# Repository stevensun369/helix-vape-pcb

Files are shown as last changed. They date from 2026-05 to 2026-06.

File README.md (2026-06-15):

# Helix Vape — Power Board

KiCad hardware design for the **Helix** temperature-control vape mod: a single-cell, USB-C powered board capable of delivering **1.0–10 V at up to 80 W** into a heating coil, with closed-loop current/voltage sensing and an ESP32-C6 running the [Helix-FW](https://github.com/stevensun369/helix-vape-fw) firmware.

The power stage is based on TI's **PMP20410** reference design, re-implemented and integrated with the MCU, sensing, and user-interface circuitry on a single board.

## Renders

| Front | Back |
|---|---|
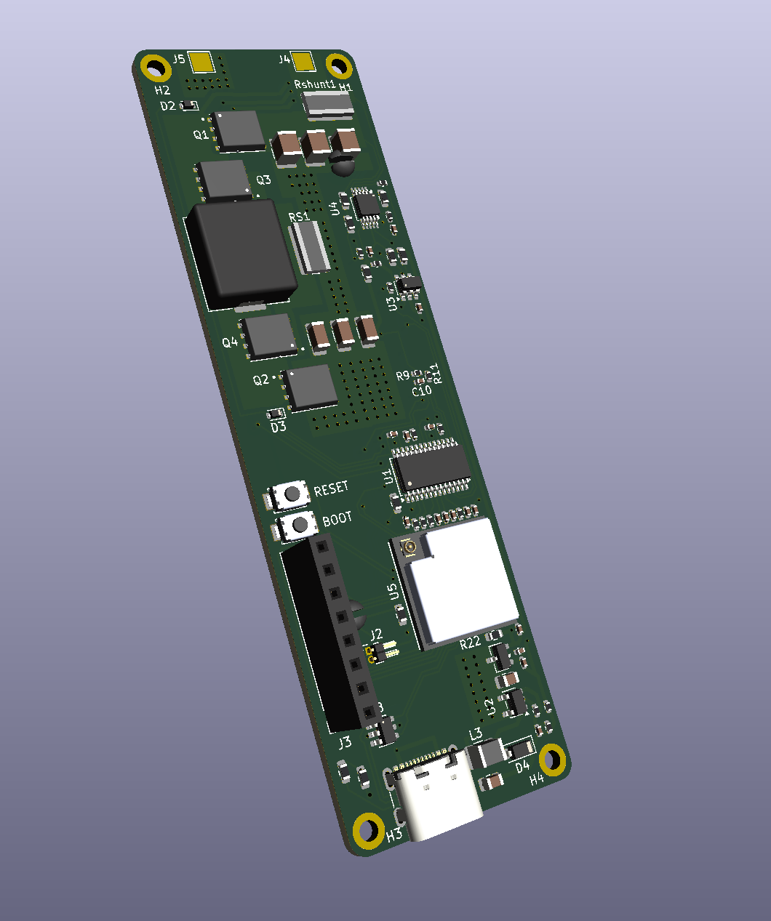
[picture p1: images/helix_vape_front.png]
Front render
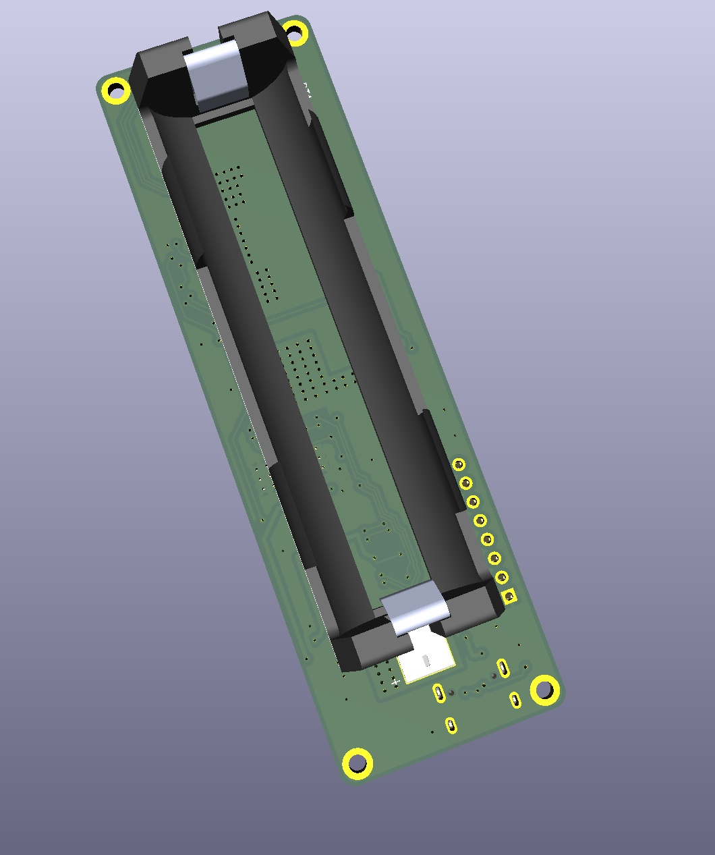
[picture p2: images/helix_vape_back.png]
Back render
|  |  |

## Schematics

| Power & analog front-end | MCU & digital |
|---|---|
| Power schematic | MCU schematic |

> Click either schematic to open the full-size SVG.

## How It Works

The board is a **digitally-controlled buck-boost regulator**. The MCU sets a target output via a DAC that injects into the regulator's feedback node, the ADC measures the actual coil current and voltage, and the firmware closes the loop with a PID controller. Because the regulator both bucks and boosts, it can hold a precise output regardless of where the battery sits in its discharge curve.

```
USB-C / Battery ──► LM5175 Buck-Boost ──► Q1–Q4 Power FETs ──► Coil
                         ▲                        │
                    MCP4726 DAC          RS1 / Rshunt sense
                         │                        │
                    ESP32-C6 ◄──────── ADS1015 ADC
```

## Key Components

| Ref | Part | Function |
|-----|---|---|
| U1 | **LM5175PWP** | 4-switch synchronous buck-boost controller — the main 80 W power stage |
| U5 | **ESP32-C6-MINI-1U** | RISC-V MCU + Wi-Fi/BLE module; runs the control loop, UI, and safety logic |
| U4 | **ADS1015IDGS** | 12-bit I²C ADC — differential coil-current sensing plus single-ended Vout/Vbat |
| U3 | **MCP4726** | 12-bit I²C DAC — injects into the LM5175 feedback node to set output (inverse scaling) |
| Q1–Q4 | **BSC010NE2LSI** | 25 V, ~1 mΩ power MOSFETs — the buck-boost switching bridge |
| U2 | **LMR62014XMF** | Boost regulator for the auxiliary/gate-drive rail |
| U6 | **LP3986-30B3F** | 3.0 V LDO — clean rail for the MCU and analog parts |
| U8 | **USBLC6-2SC6** | USB-C data-line ESD / TVS protection |
| J1 | **USB-C Receptacle (16P)** | Charging and power input |
| RS1 / Rshunt1 | **2 mΩ / 10 mΩ shunts** | High-side and coil current sensing |
| L1 | **680 nH, 23 A** | Main power inductor (Chilisin) |
| BT1 | **1042 cell** | Battery connection |
| SW1 / SW2 | Push buttons | User input |

Full bill of materials with LCSC part numbers is in [`PRODUCTION_FILES/BOM-helix_vape.csv`](PRODUCTION_FILES/BOM-helix_vape.csv).

## Design Notes

- **Inverse DAC feedback:** higher DAC voltage produces *lower* output, so any logical fault or DAC reset biases the regulator toward a safe low-power idle (~1.0 V) rather than full power.
- **Shared I²C bus @ 400 kHz** ties together the ADC and DAC; the firmware arbitrates access to keep latency predictable under contention.
- **Differential current sensing** through the ADS1015 gives the firmware accurate, real-time coil current for PID power control and over-current safety.

## Files

| Path | Contents |
|---|---|
| `helix_vape.kicad_pro` / `.kicad_sch` / `.kicad_pcb` | KiCad project, schematics, and board layout |
| `mcu.kicad_sch` | MCU subsheet |
| `PRODUCTION_FILES/` | Gerbers, BOM, and CPL (pick-and-place) for JLCPCB |
| `jlcpcb/` | JLCPCB fabrication / assembly outputs |
| `images/` | 3D renders and exported schematics |

## Manufacturing

Production files target **JLCPCB** assembly:

- `PRODUCTION_FILES/GERBER-helix_vape.zip` — fabrication Gerbers
- `PRODUCTION_FILES/BOM-helix_vape.csv` — bill of materials (LCSC part numbers)
- `PRODUCTION_FILES/CPL-helix_vape.csv` — component placement / pick-and-place

## Firmware

The board is driven by [Helix-FW](https://github.com/stevensun369/helix-vape-fw), an async Rust (Embassy) firmware with a host-testable safety and control logic core.

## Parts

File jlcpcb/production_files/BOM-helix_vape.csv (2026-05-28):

Comment | Designator | Footprint | LCSC | Quantity
0 | R7 | R_0402_1005Metric | C881153 | 1
0.022uF | C8 | C_0402_1005Metric | C107019 | 1
0.047uF | C7 | C_0402_1005Metric | C285062 | 1
0.1uF | C20,C22,C23 | C_0402_1005Metric | C1525 | 3
0.1uF | C2,C5,C9 | C_0402_1005Metric | C85858 | 3
0.22uF | C3,C6 | C_0402_1005Metric | C696915 | 2
1.5k | R5 | R_0402_1005Metric | C308014 | 1
10 | R1,R2,R3 | R_0402_1005Metric | C176108 | 3
100 | R11,R9 | R_0402_1005Metric | C82865 | 2
100k | R28 | R_0603_1608Metric | C25803 | 1
100pF | C1,C11 | C_0402_1005Metric | C281751 | 2
1042 | BT1 | BAT_1042 | C5249310 | 1
10k | R22,R23,R4,R6 | R_0603_1608Metric | C25804 | 4
10m | Rshunt1 | R_1225_3264Metric | C304202 | 1
10uH | L3 | L_1210_3225Metric | C22469024 | 1
120k | R26 | R_0603_1608Metric | C25808 | 1
130k | R13 | R_0402_1005Metric | C881362 | 1
16.2k | R16 | R_0402_1005Metric | C27176 | 1
1uF | C4 | R_0402_1005Metric | C29266 | 1
2.2uF | C24,C25 | C_0402_1005Metric | C12530 | 2
200k | R29 | R_0402_1005Metric | C25811 | 1
20k | R14 | R_0402_1005Metric | C5157652 | 1
220pF | C10 | C_0402_1005Metric | C1530 | 1
22uF | Cout1,Cout2,Cout3 | C_1210_3225Metric | C2918511 | 3
22uF | Cin1,Cin2,Cin3 | C_1206_3216Metric | C87996 | 3
2m | RS1 | R_1225_3264Metric | C7463342 | 1
4.7k | R24,R25 | R_0603_1608Metric | C23162 | 2
4.7uF | Cin4,Cout6 | C_0805_2012Metric | C107365 | 2
47 | R8 | R_0603_1608Metric | C23182 | 1
47k | R27 | R_0402_1005Metric | C25819 | 1
49.9k | R10 | R_0603_1608Metric | C23184 | 1
49.9k | R18 | R_0402_1005Metric | C3008853 | 1
5.1k | R20,R21 | R_0603_1608Metric | C14677 | 2
5.49k | R15 | R_0402_1005Metric | C407675 | 1
560pF | C14 | C_0402_1005Metric | C107029 | 1
6.98k | R19 | R_0402_1005Metric | C852901 | 1
680nH, 23A, 30A Isat | L1 | L_Chilisin_BMRF00101040 | C2921223 | 1
68pF | C13 | C_0402_1005Metric | C76977 | 1
ADS1015IDGS | U4 | TSSOP-10_3x3mm_P0.5mm | C193969 | 1
BASS516,115 | D2,D3 | D_SOD-523 | C10037 | 2
BSC010NE2LSI | Q1,Q2,Q3,Q4 | TRANS_BSC010NE2LSI | C534282 | 4
ESP32-C6-MINI-1U | U5 | MOD53_ESP32-C6-MINI-1U_EXP | C20627095 | 1
LM5175PWP | U1 | HTSSOP-28-1EP_4.4x9.7mm_P0.65mm_EP3.4x9.5mm_ThermalVias | C113356 | 1
LMR62014XMF | U2 | SOT-23-5 | C468235 | 1
LP3986-30B3F | U6 | SOT-23-3 | C387690 | 1
MBR0520LT1G | D4 | D_SOD-123 | C23848 | 1
MCP4726 | U3 | SOT-23-6 | C191581 | 1
SW_Push | SW1,SW2 | SW_TS-1088-AR02016 | C720477 | 2
USB-C Receptacle 16P | J1 | USB_C_Receptacle_GCT_USB4105-xx-A_16P_TopMnt_Horizontal | C2765186 | 1
USBLC6-2SC6 | U8 | SOT-23-6 | C7519 | 1
510 Power | J4 | TestPoint_Pad_2.5x2.5mm |  | 1
510 Ground | J5 | TestPoint_Pad_2.5x2.5mm |  | 1
Fire Button | J2 | PinHeader_1x02_P2.54mm_Vertical |  | 1
OLED 0.96" Display | J3 | PinHeader_1x08_P2.54mm_Vertical |  | 1

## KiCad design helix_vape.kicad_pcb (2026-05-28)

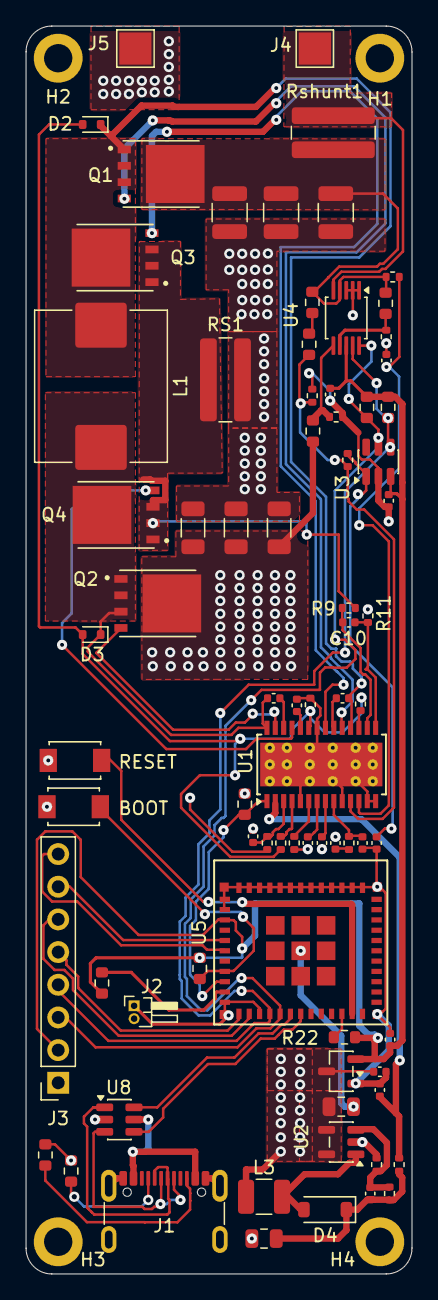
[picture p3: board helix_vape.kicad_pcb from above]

Board: 2 copper layers, 30.0 x 97.0 mm, 83 parts (1 on the bottom side), 54 nets.

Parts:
BT1: 1042; BAT_1042
C1, C11: 100pF; C_0402_1005Metric
C2, C5, C9, C20, C22, C23: 0.1uF; C_0402_1005Metric
C3, C6: 0.22uF; C_0402_1005Metric
C4: 1uF; R_0402_1005Metric
C7: 0.047uF; C_0402_1005Metric
C8: 0.022uF; C_0402_1005Metric
C10: 220pF; C_0402_1005Metric
C13: 68pF; C_0402_1005Metric
C14: 560pF; C_0402_1005Metric
C24, C25: 2.2uF; C_0402_1005Metric
Cin1, Cin2, Cin3: 22uF; C_1206_3216Metric
Cin4: 4.7uF; C_0805_2012Metric
Cout1, Cout2, Cout3: 22uF; C_1210_3225Metric
Cout6: 4.7uF; C_0805_2012Metric
D2, D3: BASS516,115; D_SOD-523
D4: MBR0520LT1G; D_SOD-123
H1, H2, H3, H4: MountingHole_Pad; MountingHole_2.2mm_M2_DIN965_Pad
J1: USB-C Receptacle 16P; USB_C_Receptacle_GCT_USB4105-xx-A_16P_TopMnt_Horizontal
J2: Fire Button; PinHeader_1x02_P1.00mm_Horizontal
J3: OLED 0.96" Display; PinSocket_1x08_P2.54mm_Vertical
J4: 510 Power; TestPoint_Pad_2.5x2.5mm
J5: 510 Ground; TestPoint_Pad_2.5x2.5mm
L1: 680nH, 23A, 30A Isat; L_Chilisin_BMRF00101040
L3: 10uH; L_1210_3225Metric
Q1, Q2, Q3, Q4: BSC010NE2LSI; TRANS_BSC010NE2LSI
R1, R2, R3: 10; R_0402_1005Metric
R4, R6, R22, R23: 10k; R_0603_1608Metric
R5: 1.5k; R_0402_1005Metric
R7: 0; R_0402_1005Metric
R8: 47; R_0603_1608Metric
R9, R11: 100; R_0402_1005Metric
R10: 49.9k; R_0603_1608Metric
R13: 130k; R_0402_1005Metric
R14: 20k; R_0402_1005Metric
R15: 5.49k; R_0402_1005Metric
R16: 16.2k; R_0402_1005Metric
R18: 49.9k; R_0402_1005Metric
R19: 6.98k; R_0402_1005Metric
R20, R21: 5.1k; R_0603_1608Metric
R24, R25: 4.7k; R_0603_1608Metric
R26: 120k; R_0603_1608Metric
R27: 47k; R_0402_1005Metric
R28: 100k; R_0603_1608Metric
R29: 200k; R_0402_1005Metric
RS1: 2m; R_1225_3264Metric
Rshunt1: 10m; R_1225_3264Metric
SW1, SW2: SW_Push; SW_TS-1088-AR02016
U1: LM5175PWP; HTSSOP-28-1EP_4.4x9.7mm_P0.65mm_EP3.4x9.5mm_ThermalVias
U2: LMR62014XMF; SOT-23-5
U3: MCP4726; SOT-23-6
U4: ADS1015IDGS; TSSOP-10_3x3mm_P0.5mm
U5: ESP32-C6-MINI-1U; MOD53_ESP32-C6-MINI-1U_EXP
U6: LP3986-30B3F; SOT-23-3
U8: USBLC6-2SC6; SOT-23-6

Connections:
+3V3: C20.1, C23.1, C25.1, J3.2, R4.1, R22.1, R23.1, R24.1, R25.1, U3.3 (VDD), U4.8 (VDD), U5.3 (3V3), U6.2 (VO)
+5V: J1.A4 (VBUS), J1.A9 (VBUS), J1.B4 (VBUS), J1.B9 (VBUS), U8.5 (VBUS)
+10V: C14.1, Cout6.1, D4.1 (K), R2.1, R18.1
ADC_IN: R28.2, R29.1, U4.6 (AIN2)
ADC_OUT: R26.2, R27.1, U4.7 (AIN3)
ADC_SH_IN: Cout1.1, Cout2.1, Cout3.1, Q1.5_8, R1.1, R8.1, R26.1, Rshunt1.1, U4.4 (AIN0)
ADC_SH_OUT: J4.1 (Pin_1_1), Rshunt1.2, U4.5 (AIN1)
BIAS: C3.1, U1.24 (BIAS)
BOOT: SW1.1, U5.23 (IO9)
BOOT1: C9.2, U1.26 (BOOT1)
BOOT2: C5.2, U1.20 (BOOT2)
COMP: C8.1, R5.2, U1.9 (COMP)
CONV_FB: C22.1, R16.2, U3.1 (VOUT)
CS: C10.1, R9.1, U1.16 (CS)
CSG: C10.2, R11.1, U1.15 (CSG)
EN: R6.1, U1.1 (EN/UVLO), U5.9 (IO4)
FB: R10.2, R15.1, R16.1, U1.11 (FB)
FIRE: J2.2, R4.2, U5.10 (IO5)
GND: BT1.N, C1.2, C2.2, C3.2, C4.2, C6.2, C7.2, C8.2, C11.2, C13.2, C20.2, C22.2, C23.2, C24.2, C25.2, Cin1.2, Cin2.2, Cin3.2, Cin4.2, Cout1.2, Cout2.2, Cout3.2, Cout6.2, H1.1 (1_1), H2.1 (1_1), H3.1 (1_1), H4.1 (1_1), J1.A1 (GND), J1.A12 (GND), J1.B1 (GND), J1.B12 (GND), J1.SH (SHIELD), J2.1, J3.1, J5.1 (Pin_1_1), R6.2, R11.2, R13.2, R15.2, R19.2, R20.2, R21.2, R27.2, R29.2, RS1.2, SW1.2, SW2.2, U1.5 (DITH), U1.10 (AGND), U1.13 (ISNS(-)), U1.14 (ISNS(+)), U1.22 (PGND), U1.29 (PowerPAD), U2.2 (GND), U3.2 (VSS), U4.1 (ADDR), U4.2 (ALERT/RDY), U4.3 (GND), U5.1 (GND), U5.2 (GND), U5.11 (GND), U5.14 (GND), U5.36 (GND), U5.37 (GND), U5.38 (GND), U5.39 (GND), U5.40 (GND), U5.41 (GND), U5.42 (GND), U5.43 (GND), U5.44 (GND), U5.45 (GND), U5.46 (GND), U5.47 (GND), U5.48 (GND), U5.49 (GND), U5.50 (GND), U5.51 (GND), U5.52 (GND), U5.53 (GND), U6.1 (GND), U8.2 (GND)
HDRV1: Q2.4, U1.27 (HDRV1)
HDRV2: Q1.4, U1.19 (HDRV2)
K1: J3.5, U5.12 (IO0)
K2: J3.6, U5.13 (IO1)
K3: J3.7, U5.5 (IO2)
K4: J3.8, U5.6 (IO3)
LDRV1: Q4.4, U1.25 (LDRV1)
LDRV2: Q3.4, U1.21 (LDRV2)
MODE: R7.2, U1.4 (MODE)
unnamed: C7.1, R5.1
unnamed: D4.2 (A), L3.2, U2.1 (SW)
unnamed: J1.A5 (CC1), R20.1
unnamed: J1.B5 (CC2), R21.1
unnamed: J1.A6 (D+), J1.B6 (D+), U8.3 (I/O2)
unnamed: J1.A7 (D-), J1.B7 (D-), U8.1 (I/O1)
unnamed: R8.2, R10.1
unnamed: R14.2, U1.17 (PGOOD)
unnamed: C13.1, U1.7 (SLOPE)
unnamed: C14.2, R18.2, R19.1, U2.3 (FB)
unnamed: R22.2, U5.22 (IO8)
RESET: R23.2, SW2.1, U5.8 (EN)
SCL: J3.3, R25.2, U3.5 (SCL), U4.10 (SCL), U5.16 (IO7)
SDA: J3.4, R24.2, U3.4 (SDA), U4.9 (SDA), U5.15 (IO6)
SS: C6.1, U1.8 (SS)
SW1: C9.1, D3.1 (K), L1.1, Q2.1, Q2.2, Q2.3, Q4.5_8, U1.28 (SW1)
SW2: C5.1, D2.1 (K), L1.2, Q1.1, Q1.2, Q1.3, Q3.5_8, U1.18 (SW2)
SYNC: R13.1, U1.6 (RT/SYNC)
USB_D+: U5.18 (IO13), U8.4 (I/O2)
USB_D-: U5.17 (IO12), U8.6 (I/O1)
VCC: C4.1, D2.2 (A), D3.2 (A), R7.1, R14.1, U1.23 (VCC)
VIN: BT1.P, C24.1, Cin1.1, Cin2.1, Cin3.1, Cin4.1, L3.1, Q2.5_8, R3.1, R28.1, U2.4 (EN), U2.5 (VIN), U6.3 (VI)
VIN_IC: C2.1, R2.2, U1.2 (VIN)
VISNS: C11.1, R3.2, U1.3 (VISNS)
VOSNS: C1.1, R1.2, U1.12 (VOSNS)
VRS: Q3.1, Q3.2, Q3.3, Q4.1, Q4.2, Q4.3, R9.2, RS1.1

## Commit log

2026-05-28 had some problems
    [BOM-helix_vape.csv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]
2026-06-15 Add README with chip overview, schematics, and renders
2026-06-15 Add white background to schematic SVGs
